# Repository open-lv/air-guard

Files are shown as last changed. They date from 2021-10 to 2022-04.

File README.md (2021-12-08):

# Air Guard 💨



Air Guard is a do-it-yourself electronics kit for building an **air quality monitor** for your school, home or office.

## Project Goals

Create a kit of electronics components, software tools and instructions for kids (and anyone) to create air quality monitors for their living spaces using affordable and readily available components and friendly programming tools.

## Design Goals

- Use existing electronics modules for all components to ensure the parts are available and affordable.

- Build on the experience of other electronics platforms such as [micro:bit](https://microbit.org), [M5Stack](https://m5stack.com), [MicroPython](https://micropython.org), [ESPHome](https://esphome.io) which provide user-friendly tools and concepts for exploring the hardware and software features.

- Allow space for customization and creative expression to encourage use and ownership of the devices.

- Let users experience quick wins early to encourage continued exploration.

- Design for groups of people building the kit and splitting responsibilities.

## Technical Design

- Rely on permanent power supply over USB to avoid limiting the available sensor components (due to their power consumption) and to encourage creative expression in software through the use of LEDs, buzzers and displays. See [issue #4](https://github.com/open-lv/air-guard/issues/4) for the discussion around energy usage.

- Use [MicroPython](https://micropython.org) as the software platform due to the available tooling and accessible programming environments. See [issue #6](https://github.com/open-lv/air-guard/issues/6) for discussion.

- Use ESP32 based microcontrollers due to extensive support for MicroPython and the selected sensor components, and affordable development kits. See [issue #7](https://github.com/open-lv/air-guard/issues/7) for the suggested bill of materials.

## Contribute

Join our [chat on Gitter](https://gitter.im/open-lv/air-guard) to discuss ways to contribute. Issues and pull requests are always welcome!

## Credits

Created [by contributors](https://github.com/open-lv/air-pilot/graphs/contributors).

## License

This is an open source project where the [software](software) and [documentation](docs) are licensed under [MIT](LICENSE) while [the hardware](hardware) is licensed under [CC BY-NC-SA 4.0](hardware/LICENSE).

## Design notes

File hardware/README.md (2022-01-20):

# GAISA SARGS Hardware

GAISA SARGS proto image

GAISA SARGS is an open source air quality monitor DIY kit for kids & teenagers.

Current revision: **03**

Known bugs: **none yet**

Authors: **Skrubis & Zahars Ze**

The project consists of 3 PCBs you need to order:
1) [The main PCB x1 ](https://github.com/open-lv/air-guard/tree/main/hardware/main-pcb) 
2) [The side PCB x2 ](https://github.com/open-lv/air-guard/tree/main/hardware/side-pcb)
3) [The rear PCB x1 ](https://github.com/open-lv/air-guard/tree/main/hardware/rear-pcb)

If you want to practice soldering, feel free to order some "friend" PCBs:
[DRAUGS PCB ](https://github.com/open-lv/air-guard/tree/main/hardware/draugs-pcb)

The PCBs are drawn in Kicad 5.1.x
The schematic of the main board: [airguard_v1.pdf](https://github.com/open-lv/air-guard/blob/main/hardware/main-pcb/airguard_v1.pdf)

All boards are your run of the mill pcbhouse 
(OSH, pcbway, jlcpcb, etc.) standard process compatible. 

Just upload the Gerber ZIP file and choose the options specified below:

Layers: 2

Thicness: 1.6mm

Soldermask color: Blue 
(as intended by the artist Zahars Ze, however we invite you to experiment and show us the results)

Surface finish: RoHS HASL
if used by kids; show us how it looks in ENIG, if you ever make one

The DIY kit BOM can be viewed in the BOM folder, however at this time it is very preliminary in nature. 
Most likely not much will change, but please keep it in mind while viewing it.

**The simple BOM is as follows**:
1) Main PCB - x1
2) Side PCB - x2
3) Rear PCB - x1
4) 19pin 2.54mm female header - x2
5) ESP-32 DevkitC V4 or older version (check pinouts in the main pcb schematic) - x1
6) 4pin 2.54mm female header - x1
7) 5pin 2.54mm female header - x1
8) Winsen MHZ19-C (or -B) - x1
9) 4.7k TH Resistor - x9
10) 2N2222 NPN transistor TO-92 or similar - x4
11) 10mm TH LED Green - 1x
12) 10mm TH LED Red - 1x
13) 10mm TH LED Orange(Yellow) - 1x
14) 3mm TH LED White - 2x
15) 68R TH Resistor - 3x
16) 33R TH Resistor - 2x
17) Buzzer 10mm pin to pin - 1x
18) Standard TH push button 6mm - 1x
19) SSD1306 based I2C OLED 0.96" 128x64px - 1x - check voltage and pinout on the pcb!!
20) 220uF electrolytic capacitor(6.3x11, 25+V)

That's it! It's a very simple project electroncis wise, so feel free to experiment, customize or improve it!

This portion of the project is licensed under [CC BY-NC-SA 4.0](hardware/LICENSE).

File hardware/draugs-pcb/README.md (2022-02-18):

# GAISA SARGS DRAUGS

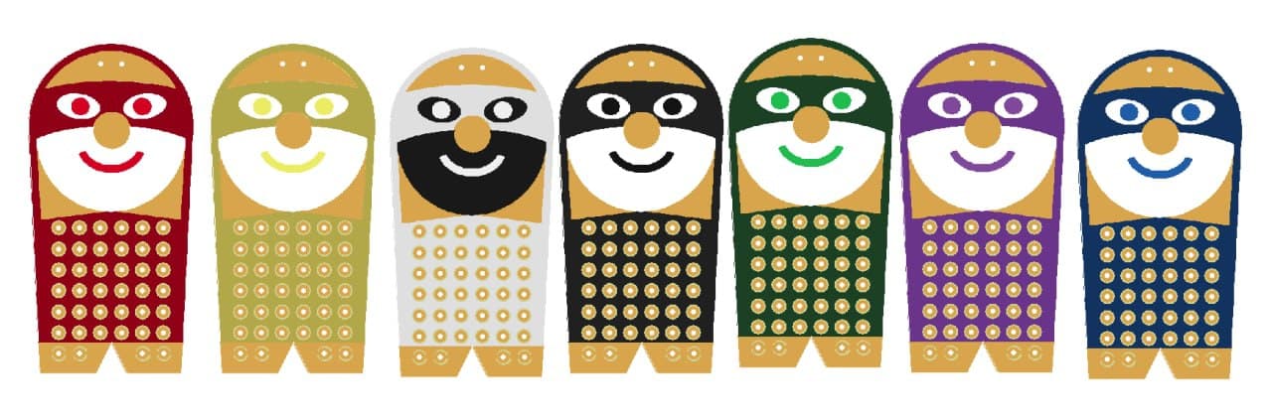
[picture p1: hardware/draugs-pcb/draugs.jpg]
GAISA SARGS draugs


GAISA SARGS DRAUGS is a "learn to solder" PCB

Current revision: **0**

Known bugs: **none yet**

Authors: **Skrubis & Zahars Ze**

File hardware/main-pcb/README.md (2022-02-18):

# GAISA SARGS R03

Version 3 hardware, designed in Kicad 5
by 
SKRUBIS & ZAHARS ZE

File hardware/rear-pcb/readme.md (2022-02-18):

# GAISA SARGS R03 REAR PCB

This pcb acts as a cover for the NDIR CO2 sensor, which may be sensitive to direct sunlight

Version 3 hardware, designed in Kicad 5
by 
SKRUBIS & ZAHARS ZE

KNOWN BUGS: JLCPCB gerber viewer doesn't show or detect the outline, use stackup.txt (found in gerber archive) to specify those

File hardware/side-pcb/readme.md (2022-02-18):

# GAISA SARGS R03 SIDE PCB

This pcb acts as a cover for the NDIR CO2 sensor, which may be sensitive to direct sunlight

You need two of these for one airguard
The slot shape on the side accounts for loose interpretations of Espressifs ESP32 DEVKIT C (may be a bit longer than that of the original design)

Version 3 hardware, designed in Kicad 5
by 
SKRUBIS & ZAHARS ZE

KNOWN BUGS: JLCPCB gerber viewer doesn't show or detect the outline, use stackup.txt (found in gerber archive) to specify those

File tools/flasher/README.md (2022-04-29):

# Air Guard ESP32 Flasher

See [`flash.sh`](./flash.sh) which flashes the core MicroPython firmware and the Air Guard script files. Run it on your local machine if you have `esptool.py`, `ampy` and 'jq' installed or use the included Docker environment. If needed, use brew to add what's missing to your local environment (e.g. 'brew install jq'). 

## Flashing Locally

Install the required Python packages defined in [requirements.txt](./requirements.txt):

    pip install -r requirements.txt

Note that you might need to replace `pip` with `pip3` in the command above depending on your operating system.

Now run the flashing tool which will automatically download the required version of MicroPython firmware, flash it to the device and upload all `*.py` files from the `firmware/micropyhton` directory to the device:

    ESPTOOL_PORT=/dev/tty.usbserial ./flash.sh

where `ESPTOOL_PORT` is the environment variable pointing to the UART port path `/dev/tty.usbserial` with the ESP32 device attached.

## Flashing Using Docker

Note that mounting USB ports inside Docker containers is only supported on Linux host computers. Docker on MacOS and Windows doesn't support this.

Run `docker-compose build` to build the Docker container with the appropriate version of `esptool.py` and `ampy`.

Run `ESPTOOL_PORT=/dev/tty.usbserial docker-compose run --rm flash` to flash the firmware where `/dev/tty.usbserial` is the UART device port path. Alternatively, use the `.env` file to set the `ESPTOOL_PORT` environment variable which will be picked up by `docker-compose` automatically.

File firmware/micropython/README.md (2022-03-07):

MicroPython version of air-guard firmware
--------------------------------------------

The firmware is quite basic at the moment:

  * MHZ19C readings are performed as per datasheet. It appears that during heating phase, it returns a value of 500 (which is misleading and should not be presented to user)
  * main.py intentionally contains the "main" logic, while everything else is hidden under sargs.py. A separate thread is started when importing sargs.py which will handle all the 
  background functionality (re-drawing the screen, connecting to WiFi, publishing readings over MQTT etc)
  * There is comprehensive logging to serial console- do check the console output if something is not working as expected

Startup error conditions
-------------------

  * Blinking red LED: I2C OLED not responding
  * Blinking yellow LED: CO2 sensor not responding

Configuration
----------------------

To enable WiFi functionality, copy the config.json.example file to config.json and enter the configuration details in the file.

To enable publishing to ThingSpeak channel, fill in the following configuration in config.json:
    
  * mqttClientId = "ThingSpeak client ID"
  * mqttPassword = "ThingSpeak MQTT device password"
  * mqttTsId = "ThingSpeak channel ID"
  * mqttClass = "ThingspeakMQTTClient"

CO2 sensor calibration
--------------------------

Manually triggered 400ppm point calibration is implemented. To use it, make sure the sensor is exposed
to ~400ppm (fresh air, outside) for at least 20 minutes before and after starting the calibration.

To start calibration, press the button for at least 5 seconds, then select "Yes" button on confirmation dialog with a short press,
then confirm the start of calibration by long press when "Yes" button is selected.

MicroPython version
-------------------------

This firmware is developed against MicroPython for ESP32 v1.17.

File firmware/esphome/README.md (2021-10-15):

# ESPHome Firmware for Air Guard

See [`air-guard.yaml`](air-guard.yaml) for the firmware configuration.

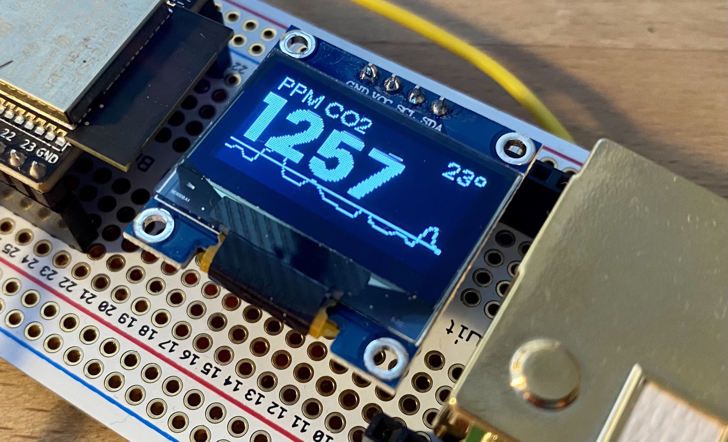
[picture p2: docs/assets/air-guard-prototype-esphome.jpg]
ESPHome showing CO2 sensor values on a display


## Requirements

See the [ESPHome setup instructions](https://esphome.io/guides/getting_started_command_line.html) for how to install the required tooling to compile and upload the firmware. Alternatively, see the "Build and Upload" section below for how to use the ESPHome Docker container to build and upload the firmware.

## Setup

The following pins are used to attach sensors and devices to ESP32:

- MH-Z19B CO2 sensor is connected to UART pins 16 for RX and 17 for TX.
- SSD1306 OLED display is connected to the I2C pins 21 for SDA and 22 for SCL.

## Build and Upload

Copy `secrets.yaml.example` to `secrets.yaml` and configure your WiFi name and password.

Run the following command to build and upload the firmware using the [`esphome` command-line utility](https://esphome.io/guides/cli.html):

    esphome run air-guard.yaml

Alternatively, use the ESPHome Docker container to do the same:

    docker run --rm --volume "${PWD}":/config --device=/dev/ttyUSB0 --privileged --interactive --tty esphome/esphome run air-guard.yaml

where `/dev/ttyUSB0` is the absolute path to the serial interface on the host computer to be shared with the Docker container for uploading the firmware. The `--privileged` flag might not be necessary depending on your operating system and Docker configuration.

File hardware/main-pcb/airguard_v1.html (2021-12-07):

# C:\Users\Work\Desktop\air-guard-non-square\hardware\airguard_v1.sch

11/09/21 10:31:13 PM

Eeschema (5.1.10)-1

Component Count:39

Ref | Qnty | Value | Part | Datasheet | Description | Vendor
BZ1 | 1 | Buzzer | Device:Buzzer | ~ | Buzzer, polarized
DZELTENS1 | 1 | LED_YELLOW | Device:LED | ~ | Light emitting diode
J1, J3 | 2 | Conn_01x04_Female | Connector:Conn_01x04_Female | ~ | Generic connector, single row, 01x04, script generated (kicad-library-utils/schlib/autogen/connector/)
J2 | 1 | Conn_01x05_Female | Connector:Conn_01x05_Female | ~ | Generic connector, single row, 01x05, script generated (kicad-library-utils/schlib/autogen/connector/)
J4, J5 | 2 | Conn_01x19_Female | Connector:Conn_01x19_Female | ~ | Generic connector, single row, 01x19, script generated (kicad-library-utils/schlib/autogen/connector/)
Q1, Q2, Q3, Q4 | 4 | PN2222A | Transistor_BJT:PN2222A | https://www.onsemi.com/pub/Collateral/PN2222-D.PDF | 1A Ic, 40V Vce, NPN Transistor, General Purpose Transistor, TO-92
R1, R2, R3, R4, R6, R7, R8, R9, R10 | 9 | R 4.7K | Device:R | ~ | Resistor
R5 | 1 | R_PHOTO 8-20kR | Device:R_PHOTO | ~ | Photoresistor
R11, R12, R13 | 3 | 68R | Device:R | ~ | Resistor
SARKANS1 | 1 | LED_RED | Device:LED | ~ | Light emitting diode
SW1 | 1 | SW_Push | Switch:SW_Push | ~ | Push button switch, generic, two pins
U1 | 1 | MH-Z19B | mh_z19b:MH-Z19B
U2 | 1 | ESP32_DEVKIT_C | esp32_devkitc:ESP32_DEVKIT_C
U3 | 1 | SSD1306 | SSD1306-128x64_OLED:SSD1306
U4, U5, U6, U7, U8, U9 | 6 | Solder-rib-main | gaisa-sargs-0:Solder-rib-main
U10 | 1 | ART-FCOPPER | gaisa-sargs-0:ART
U11 | 1 | ART-FSILK | gaisa-sargs-0:ART
U12 | 1 | ART-FMASK | gaisa-sargs-0:ART
ZAĻŠ1 | 1 | LED_GREEN | Device:LED | ~ | Light emitting diode

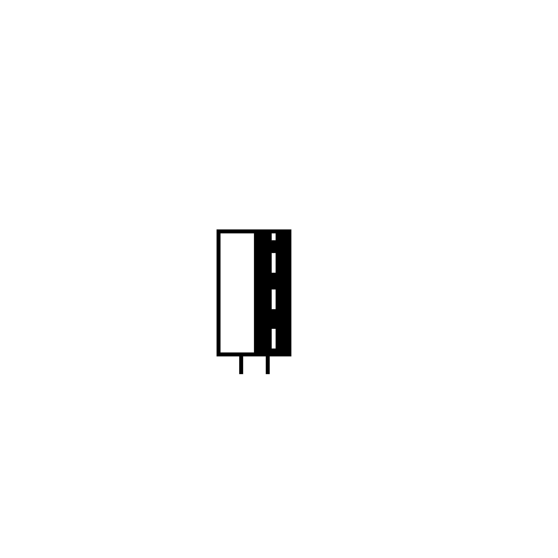
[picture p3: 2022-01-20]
hardware/main-pcb/pcbart/cancap/.svg2shenzhen-cache/images/F.SilkS_g8889.png

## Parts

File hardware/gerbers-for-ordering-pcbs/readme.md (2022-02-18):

Use these archives to order copies.
Inspect the archives for stackup.txt to find out what options you should choose for the PCB house.

Known bugs: JLCPCB viewer doesn't find the outline for side and rear PCBs, refer to the stackup.txt file

Possible PCB fab houses: OSHPARK, JLCPCB, PCBWAY, ALLPCB, DIRTYPCBS, EUROCIRCUITS, AISLER, ETC

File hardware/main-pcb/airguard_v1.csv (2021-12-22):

Reference | Value | Footprint | Datasheet | LCSC | LCSC URL | MPN | SOURCE
U2 | ESP32_DEVKIT_C | footprints:ESP32_DEVKIT_C
U1 | MH-Z19B | footprints:Winsen_MH-Z19B
U3 | SSD1306 | footprints:SSD1306
Q2 | PN2222A | TO_SOT_Packages_THT:TO-92_Molded_Wide | https://www.onsemi.com/pub/Collateral/PN2222-D.PDF | C118536 | https://lcsc.com/product-detail/Bipolar-Transistors-BJT_ST-Semtech-2N2222A_C118536.html
SARKANS1 | LED_RED | LEDs:LED_D10.0mm | ~ |  |  | szczine | szczine@163.com
R11 | 68R | Resistors_ThroughHole:R_Axial_DIN0207_L6.3mm_D2.5mm_P10.16mm_Horizontal | ~ | C385542 | https://lcsc.com/product-detail/Through-Hole-Resistors_TyoHM-RN1-2WS68-FT-BA1_C385542.html
Q3 | PN2222A | TO_SOT_Packages_THT:TO-92_Molded_Wide | https://www.onsemi.com/pub/Collateral/PN2222-D.PDF | C118536 | https://lcsc.com/product-detail/Bipolar-Transistors-BJT_ST-Semtech-2N2222A_C118536.html
DZELTENS1 | LED_YELLOW | LEDs:LED_D10.0mm | ~ |  |  | szczine | szczine@163.com
Q4 | PN2222A | TO_SOT_Packages_THT:TO-92_Molded_Wide | https://www.onsemi.com/pub/Collateral/PN2222-D.PDF | C118536 | https://lcsc.com/product-detail/Bipolar-Transistors-BJT_ST-Semtech-2N2222A_C118536.html
ZALS1 | LED_GREEN | LEDs:LED_D10.0mm | ~ |  |  | szczine | szczine@163.com
SW1 | SW_Push | Buttons_Switches_ThroughHole:SW_PUSH_6mm_h5mm | ~ | C393938 | https://lcsc.com/product-detail/Tactile-Switches_SHOU-HAN-TS665CJ_C393938.html
J4 | Conn_01x19_Female | Oddities:Dummy_Empty | ~ | C319202 | https://lcsc.com/product-detail/Female-Headers_BOOMELE-Boom-Precision-Elec-C319202_C319202.html
J5 | Conn_01x19_Female | Oddities:Dummy_Empty | ~ | C319202 | https://lcsc.com/product-detail/Female-Headers_BOOMELE-Boom-Precision-Elec-C319202_C319202.html
J3 | Conn_01x04_Female | Oddities:Dummy_Empty | ~ | C2718488 | https://lcsc.com/product-detail/Female-Headers_BOOMELE-Boom-Precision-Elec-C2718488_C2718488.html
J1 | Conn_01x04_Female | Oddities:Dummy_Empty | ~ | C2718488 | https://lcsc.com/product-detail/Female-Headers_BOOMELE-Boom-Precision-Elec-C2718488_C2718488.html
J2 | Conn_01x05_Female |  | ~
R5 | R_PHOTO 8-20kR | Opto-Devices:Resistor_LDR_5.1x4.3_RM3.4 | ~ | C125627 | https://lcsc.com/product-detail/Photoresistors_Senba-Sensing-Tech-GL5528_C125627.html
R4 | R 4.7K | Resistors_ThroughHole:R_Axial_DIN0207_L6.3mm_D2.5mm_P10.16mm_Horizontal | ~ | C120071 | https://lcsc.com/product-detail/Through-Hole-Resistors_CCO-Chian-Chia-Elec-CF1-4W-4-7K-5-T52_C120071.html
BZ1 | BALSS | footprints:buzzer-C360606 | ~ | C360606 | https://lcsc.com/product-detail/Buzzers_S-S-SFN-1207PA5-0_C360606.html
Q1 | PN2222A | TO_SOT_Packages_THT:TO-92_Molded_Wide | https://www.onsemi.com/pub/Collateral/PN2222-D.PDF | C118536 | https://lcsc.com/product-detail/Bipolar-Transistors-BJT_ST-Semtech-2N2222A_C118536.html
R7 | R 4.7K | Resistors_ThroughHole:R_Axial_DIN0207_L6.3mm_D2.5mm_P10.16mm_Horizontal | ~ | C120071 | https://lcsc.com/product-detail/Through-Hole-Resistors_CCO-Chian-Chia-Elec-CF1-4W-4-7K-5-T52_C120071.html
R8 | R 4.7K | Resistors_ThroughHole:R_Axial_DIN0207_L6.3mm_D2.5mm_P10.16mm_Horizontal | ~ | C120071 | https://lcsc.com/product-detail/Through-Hole-Resistors_CCO-Chian-Chia-Elec-CF1-4W-4-7K-5-T52_C120071.html
R9 | R 4.7K | Resistors_ThroughHole:R_Axial_DIN0207_L6.3mm_D2.5mm_P10.16mm_Horizontal | ~ | C120071 | https://lcsc.com/product-detail/Through-Hole-Resistors_CCO-Chian-Chia-Elec-CF1-4W-4-7K-5-T52_C120071.html
R6 | R 4.7K | Resistors_ThroughHole:R_Axial_DIN0207_L6.3mm_D2.5mm_P10.16mm_Horizontal | ~ | C120071 | https://lcsc.com/product-detail/Through-Hole-Resistors_CCO-Chian-Chia-Elec-CF1-4W-4-7K-5-T52_C120071.html
R3 | R 4.7K | Resistors_ThroughHole:R_Axial_DIN0207_L6.3mm_D2.5mm_P10.16mm_Horizontal | ~ | C120071 | https://lcsc.com/product-detail/Through-Hole-Resistors_CCO-Chian-Chia-Elec-CF1-4W-4-7K-5-T52_C120071.html
R12 | 68R | Resistors_ThroughHole:R_Axial_DIN0207_L6.3mm_D2.5mm_P10.16mm_Horizontal | ~ | C385542 | https://lcsc.com/product-detail/Through-Hole-Resistors_TyoHM-RN1-2WS68-FT-BA1_C385542.html
R13 | 68R | Resistors_ThroughHole:R_Axial_DIN0207_L6.3mm_D2.5mm_P10.16mm_Horizontal | ~ | C385542 | https://lcsc.com/product-detail/Through-Hole-Resistors_TyoHM-RN1-2WS68-FT-BA1_C385542.html
R10 | R 4.7K | Resistors_ThroughHole:R_Axial_DIN0207_L6.3mm_D2.5mm_P10.16mm_Horizontal | ~ | C120071 | https://lcsc.com/product-detail/Through-Hole-Resistors_CCO-Chian-Chia-Elec-CF1-4W-4-7K-5-T52_C120071.html
R1 | R 4.7K | Resistors_ThroughHole:R_Axial_DIN0207_L6.3mm_D2.5mm_P10.16mm_Horizontal | ~ | C120071 | https://lcsc.com/product-detail/Through-Hole-Resistors_CCO-Chian-Chia-Elec-CF1-4W-4-7K-5-T52_C120071.html
R2 | R 4.7K | Resistors_ThroughHole:R_Axial_DIN0207_L6.3mm_D2.5mm_P10.16mm_Horizontal | ~ | C120071 | https://lcsc.com/product-detail/Through-Hole-Resistors_CCO-Chian-Chia-Elec-CF1-4W-4-7K-5-T52_C120071.html
J6 | Conn_01x04_Female | Oddities:Dummy_Empty | ~ | C2718488 | https://lcsc.com/product-detail/Female-Headers_BOOMELE-Boom-Precision-Elec-C2718488_C2718488.html
R15 | 33R | Resistors_ThroughHole:R_Axial_DIN0207_L6.3mm_D2.5mm_P10.16mm_Horizontal | ~ | C120071 | https://lcsc.com/product-detail/Through-Hole-Resistors_CCO-Chian-Chia-Elec-CF1-4W-4-7K-5-T52_C120071.html
D2 | LED | footprints:LED_D3.0mm | ~
R14 | 33R | Resistors_ThroughHole:R_Axial_DIN0207_L6.3mm_D2.5mm_P10.16mm_Horizontal | ~ | C120071 | https://lcsc.com/product-detail/Through-Hole-Resistors_CCO-Chian-Chia-Elec-CF1-4W-4-7K-5-T52_C120071.html
D1 | LED | footprints:LED_D3.0mm | ~

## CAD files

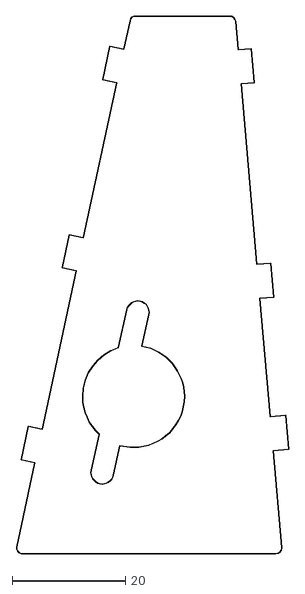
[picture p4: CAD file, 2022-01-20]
hardware/side-pcb/side-rib-3.dxf
48.1 x 94.9

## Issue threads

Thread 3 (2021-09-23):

Plates (PCB) forma un noformējums

kasparsd, 2021-09-23:
Kāda varētu būt PCB kontūra un noformējums, lai tas liktos interesants un iederētos klasēs un birojos?

Svarīgi ņemt vērā ārējo izmēru (cena) un praktiskās iespējas tādu formu saražot pietiekami mazos kvantumos, lai pieļautu izmaiņas. Pirmajām partijām varētu izmantot https://jlcpcb.com vai https://www.pcbway.com

kasparsd, 2021-09-23:
Te ir jaunākais variants, kas ir mazliet draudzīgāks par vienkārši zaļu plati:

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

martinsp, 2021-09-25:
Vai nevajadzētu samainīt vietām bateriju turētāju un radošo laukumu? Domāju, vai komponentes uz plates netraucēs rokai, lai varētu uzzīmēt/uzrakstīt kaut ko radošajā laukumā.

kasparsd, 2022-01-04:
Taisām ciet, jo šis jau ir izdarīts!

Closed 2022-01-04.

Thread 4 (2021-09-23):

CO2 sensora enerģijas patēriņš un deep-sleep atbalsts

kasparsd, 2021-09-23:
Vai kādi no pieejamajiem sensoriem piedāvā zemu enerģijas patēriņu vai deep-sleep atbalstu, lai būtu iespējams visu iekārtu darbināt tikai no 2 gab AA baterijām vismaz vienu gadu?

festlv, 2021-09-23:
1 gada darbības laiks no 2xAA baterijām ir netriviāls uzdevums, kura risināšanai var nākties pabīdīt citus constraintus (gatavu ESP32 moduļu izmantošana, viegla montāža).

Kvalitatīvās 2xAA baterijās ir ap 6Wh enerģijas. Lai gadu darbinātu no šādām baterijām, vidējam patēriņam no baterijām jābūt ~210uA@3.3V.

Sensirion SCD41 pietuvojas šim (datasheet sola 400uA vidējo patēriņu mērot reizi 5 minūtēs), bet stockā pašlaik redzu 5 gab. ar nākamajām piegādēm decembrī.

kasparsd, 2021-09-24:
Paldies par izpēti @festlv!

Izskatās, ka konkrētajam TTGO T5 modelim ir vairākas lietas, kam jāpievērš uzmanību, lai dabūtu zemu enerģijas patēriņu pat pie ESP32 deep-sleep. Te ir labs pavediens https://github.com/esphome/issues/issues/1458

1. CP2104 UART uz USB čips, kam "enable" kāja ir pie USB 5V, tāpēc cerams, ka tas vispār netiek darbināts, kad darbojas no baterijas.

2. W25Q32FW flash čipam CS kāja esot atstāta gaisā, kas nozīmē, ka pie ESP32 deep sleep tas joprojām darbojas https://github.com/esphome/issues/issues/1458#issuecomment-813915856

   > TTgo has bad energy efficiency design, biggest easy fix is a pullup on w25q32 spiflash CS pin, without it spiflash does not go to sleep even when MCU is sleeping, this has a significant impact on sleep consumption. Removing all LEDs helps also.

3. E-paper draiverim ir jāpadod speciāla komanda gulēšanai, jo citādi tas arī paliek nomodā.

Šodien mēģināju to TTGO T5 ar esphome deep-sleep, bet pieslēgtu pie USB un dabūju 9mA@5V ar ieslēgtiem LEDiem. Ar wifi un ekrāna zīmēšanu patēriņš ir pie 50-70mA @ 5V.

Domāju, ka jāsāk apsvērt micropython, jo tad varam vairāk kontrolēt izmantotās bibliotēkas, driverus un arī pašu izejas kodu. Vienīgi tad mums vajag Micropython draiverus gan ekrānam (HINK E0213A22), gan sensoriem. Nezinu, vai ir kaut kas gatavs.

kasparsd, 2021-09-24:
Un vēl viena potenciālā problēma ar TTGO T5 ir iebūvētais TP4054 lādēšanas kontrolieris, kas atbalsta tikai litija jonu akumulatorus. Tas nozīmē, ka AA baterijas nevarēs slēgt pa taisno pie esošā BAT pieslēgvietas, jo tad, pieslēdzot USB 5V, tas gribēs lādēt AA vai AAA, kā li-ion.

Anrijs, 2021-09-25:
Notestēju TTGO T5 V2.3 pie precīzāka mēraparāta. Deep-sleep rādīja 1.0-1.5mA patēriņu. Visi LED izslēgti, tukšs kods. Tajā pašā laikā, mana custom plate tērē zem 100uA.

kasparsd, 2021-09-25:
Liels paldies @Anrijs! Vai būtu iespējams pārbaudīt vai pull-ups pie W25Q32FW CS kājas tiešām samazina šo vēl 10x kā daži raksta?

Interesanti, ka [jaunākajam TTGO T5 V2.3.1](http://www.lilygo.cn/prod_view.aspx?TypeId=50031&Id=1393&FId=t3:50031:3) viņi sola 300uA:

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

Ja 90% laika tiešām ir tie 300uA un pie e-paper zīmēšanas uzlec 50mA, tad vajadzētu būt OK, ne? Vienīgi jāmāk pamodināt iekārtu no deep-sleep, kad piesprauž USB kabeli programēšanai.

> Tajā pašā laikā, mana custom plate tērē zem 100uA.

Vai tas ir ar ESP32?

Kāds ir tavas domas, ko šajā gadījumā labāk darīt, ja uzdevums prasa pēc ekrāna un plaši pieejamiem moduļiem?

Anrijs, 2021-09-25:
Pieleiku 10k pullup (lielāku uz ātro neatradu). Tagad rāda 400-500uA. Mana plate ir ar ESP32 WROOM-32D moduli.
Ja neizmanto šo TTGO gatavo risinājumu, tad jāskatās kas vispār no e-ink ir pieejams saprātīgās cenās. Ir variants zīmēt plati uz kuras to ESP32 moduli un citas komponentes salodē pa tiešo.

kasparsd, 2021-09-25:
> Tagad rāda 400-500uA.

Šis jau ir diezgan labi, ne! Vismaz tagad izklausās ticami, ka tas jaunais variants V2.3.1 sola 300uA.

Ja liek klāt SCD41 sensoru (450uA), tad sanāk ap 1mA. Ja pieliek vēl e-paper refresh reizi 5 minūtēs (pie SDC41 lasījuma), tad gan jau salasīsies visi 2mA. Ar 2000mA bačām sanāk 1000h jeb mazliet pāri mēnesim. Man šķiet pieņemami, ka reizi mēnesī kāds piespraustu sensoru pie USB aku-bankas uzlādēties.

Ar MH-Z19b gan ir trakāk, jo tam vidējais patēriņš pie ieslēgta ir ap 17mA un iesilšanas ilgums 3min. Nezinu, cik daudz viņš spētu atdzist pa piecām minūtēm, bet kopumā pat ar 50% izslēgtu barošanu sanāk lielas problēmas. Un šī ir ilustratīva problēma visiem NDIR sensoriem. Bet toties tie ir pieejami.

Ja SAFs tiešām var nodrošināt 100 gab ar SCD41, tad varētu uztaisīt savu moduli ar through-hole kājām, jo pliks virsmas montāžas sensors maksā ap EUR 30 un spriežot pēc [Seeed moduļa](https://wiki.seeedstudio.com/Grove-CO2_%26_Temperature_%26_Humidity_Sensor-SCD41/), nekādi pasīvie elementi nav vajadzīgi.

Lai nepārvērstu šo par enerģijas patēriņa optimizācijas uzdevumu, varbūt jāsāk pieņemt, ka šāds moduļveidīgs dizains pieļauj tikai pāris dienas/nedēļas/mēnešus ar baterijām un primāro lietojumu jāplāno kā iekārtu, kas pieslēgta pie patstāvīgas barošanas.

ArtursGailis1995, 2021-09-25:
Pašam ir sataisīts energo-nedraudzīgs risinājums uz ESP32, LCD, BME280, DHT22, un priekš CO2 ir MHZ-19B sensors. Diez vai šim projektam der NDIR sensori. Dati pa WiFi sūtas uz InfluxDB serveri un attēlojas ar Grafana, lai varu redzēt arī tendences, ne tikai esošos mērījumus. Viss jau pāris gadus barojas no veca iPhone lādētāja, bet varbūt šis projekts pamudinās kaut ko optimizēt vai vismaz pamērīt patēriņu.

Šāds tāds kods man ir arī Githubā, bet tur galīgi viss pa mežam, sen nav atjaunots.

kasparsd, 2021-09-25:
@ArtursGailis1995 Izskatās, ka Tev jau ir praktiski gatavs tas, ko mēģinām uzbūvēt :) Vai būtu iespējams padalīties ar bildi, kur Tev šī iekārta stāv telpā un kā izskatās?

Un smieklīgi, ka šodien tieši nolēmām atteikties no energo-efektīvā risinājuma, lai nebūtu jāoptimizē lietas, kas nav svarīgas tieši izglītības aspektam. Taisīsim slēdzamu pie patstāvīgas barošanas un tad ar visiem LEDiem un pīkstuļiem, lai jautrāk. Te ir sarakstes sākums https://gitter.im/open-lv/air-guard?at=614f51158065e87a8e027450

kasparsd, 2021-09-25:
Tā kā šodien izlēmām atteikties no bateriju barošanas, tad šo jautājumu pagaidām uzskatām par slēgtu. Ja būs vajadzība pēc bateriju darbināmas ierīces, tad arī meklēsim sensorus un komponentes, kas to atbalsta. Projekta MVP fāzē nebūtu prātīgi koncentrēties uz tehnisku optimizācijas uzdevumu, kad vēl nav saprastas kopējās prioritātes un vajadzības.

Closed 2021-09-25.

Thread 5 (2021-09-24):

Lietošanas instrukcijas un metodiskais materiāls visvienkāršākajam pielietojumam

kasparsd, 2021-09-24:
Lai samazinātu risinājuma atkarību no specializētiem rīkiem (lodāmurs) vai programnodrošinājuma (konfigurēts tool-chain), iesaku koncentrēties uz visvienkāršāko projekta pielietojumu:

1. Klase saņem un izpako komplektu, kurā ir PCB ar spraužamām ligzdām un visas komponentes -- kontrolieris, sensors, baterijas.

2. Skolēni iepazīstas ar lietošanas instrukciju un saprot, kurš modulis jāsprauž kurā vietā.

3. Tiek sasprausti moduļi un ieliktas baterijas, un ieslēgta iekārta.

4. Skolēni izdomā un uzraksta savas iekārtas nosaukumu vai logo uz atvēlētā laukuma. Novietu iekārtu tai atvēlētā vietā.

Bonus lietas:

- Grupa izrunā un izpēta, ko nozīmē "labs" gaiss, un cik daudz svaiga gaisa cilvēkam nepieciešams. Var atsaukties uz 20-30m3/h, kā to iesaka Passive House standarts.

- Grupas izpēta katru sastāvdaļu un sagatavo prezentāciju par to, kā tās strādā.

- Grupa izpēta un saprot, kādas ir atbilstošas vietas sensora novietošanai.

- Grupa izdomā stratēģiju, kā izmantot sensora datus -- ko darīt, kad sasniegtas konkrētas vērtības. Varbūt dežuranti, kas atbildīgi par datu uzraudzību un klases ventilēšanu atbilstoši izdomātajai stratēģijai?

Closed 2022-01-20.

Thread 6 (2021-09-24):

Programēšanas platforma projektam

kasparsd, 2021-09-24:
Tā kā šis ir izglītojošs projekts, tad vajadzīga tāda platforma, kuru ir viegli darbināt bez specializēta programnodrošinājuma.

Gan BBC Micro:bit, gan M5 Stack izmanto Micropython, jo tam ir sekojoši labumi:

- Ierīces atmiņā atrodas konstants firmware un lietotāja programnodrošinājums tiek definēts Python skriptos, kas glabājas kā "faili" flash atmiņā.
- Visas lietotāja programmas iespējams ielasīt, pieslēdzoties ar UART. Jebkuru programmu var rediģēt, kā arī pievienot jaunu.
- Pieejama REPL saskarsne, kas ļauj lietotājiem darbināt kontroliera funkcijas bez jauna programnodrošinājuma ielādes.
- REPL saskarsni var darbināt arī caur Web USB, izmantojot jebkuru tīmekļa pārlūku, kas to atbalsta.
- Pieejams programnodrošinājums visām operētājsistēmām, lai rediģētu un pievienotu jaunas programmas -- https://codewith.mu un https://thonny.org
- MicroPython ir Python, kas ir ļoti populāra un noderīga programēšanas valoda.

Izvēloties MicroPython, ir jāatrod vai jāuzraksta draiveri izvēlētajiem sensoriem vai arī jāizvēlas tādas komponentes, kam jau ir MicroPython atbalsts.

- ✅  Waveshare e-paper https://github.com/mcauser/micropython-waveshare-epaper
- ✅   MHZ19 ir vienkāršs PWM protokols https://github.com/antrew/mh-z19/blob/315af72d848e05c32c74d3ea930d94d15c80e227/MHZ19.cpp
- SCD41 ir labi dokumentēts i2c protokols https://github.com/Sensirion/embedded-i2c-scd4x

festlv, 2021-09-25:
Draiveru esamība/neesamība manuprāt nav iemesls, lai neizmantotu MicroPython: nepieciešamības gadījumā trūkstošais būs jāuzraksta, bet tas attiecas uz jebkuru platformu: ja projekts nebalstās uz izstrādes komandas iepriekš validētu hw/sw kombināciju, pastāv zināms risks, ka kaut kam nebūs draiveru, vai tajos nebūs realizēta vajadzīga fīča, vai būs kritiskas problēmas.

MicroPython izmantošanai profesionālā vidē es tik viegli nepiekristu, bet šāda projekta kontekstā nevaru iedomāties nevienu vērā ņemamu risku, kas izrietētu no MicroPython izmantošanas.

kasparsd, 2021-09-26:
Pēc diskusijas čatā un šeit ir nolemts izmantot MicroPython. Tas ir aprakstīts arī projekta tehniskajās vadlīnījās https://github.com/open-lv/air-guard/blob/92e274c4fb08f116cc48bd734bb726daccee3572/README.md#technical-design

Closed 2021-09-26.

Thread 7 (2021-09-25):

Materiālu saraksts (bill of materials) -- kontrolieri, sensori un barošana

kasparsd, 2021-09-25:
Provizoriskais materiālu saraksts (atjaunots 26. septembrī):

## Vietas sensoriem

- [MH-Z19b](https://www.winsen-sensor.com/sensors/co2-sensor/mh-z19b.html) CO2 sensors.
- DHT22 temperatūras un mitruma sensors.

Tukša vieta uz PCB vēl šādiem:

- [SenseAir S8](https://senseair.com/products/size-counts/s8-residential/) CO2 sensors.
- [SCD41](https://www.sensirion.com/en/environmental-sensors/carbon-dioxide-sensors/carbon-dioxide-sensor-scd4x/) CO2, temperatūras, mitruma un trokšņa sensors. Šis ir surface-mount, tāpēc vajadzīga pārejas plate vai arī atbalsts esošiem moduļiem.
- [BME280](https://randomnerdtutorials.com/dht11-vs-dht22-vs-lm35-vs-ds18b20-vs-bme280-vs-bmp180/) temperatūras un mitruma sensors.

## Barošana

Tika izlemts lietot patstāvīgu barošanu no USB, lai MVP versijā nebūtu jānodarbojas ar enerģijas patēriņa optimizācijas uzdevumu.

## Kontrolieris un ekrāns

- ESP32-DevKitC
- SSD1306 OLED ekrāns

Anrijs, 2021-09-26:
MH-Z19B/C boost vajadzēs uz 5V

kasparsd, 2021-09-26:
Izskatās, ka ESP32-DevKitC [padod USB 5V uz EXT_5V kāju](https://dl.espressif.com/dl/schematics/esp32_devkitc_v4-sch.pdf), kad pieslēgts USB:

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

Vai pareizi saprotu?

Šis, protams, der tikai tad, ja tiek lietots patstāvīgs USB pieslēgums, par kuru vakar nolēmām čatā.

Anrijs, 2021-09-26:
Ja barošana paliek tikai no USB, tad var no tā EXT 5V pin barot

kasparsd, 2021-09-27:
ESP32 devkitc piegādātāju opcijas:

- https://www.olimex.com/Products/IoT/ESP32/ESP32-DevKit-LiPo/open-source-hardware
- https://www.tme.eu/lv/details/esp32-devkitc-32d/komplekts-datu-transmisijai/espressif/
- https://www.az-delivery.de/en/products/esp-32-dev-kit-c-v4?variant=30871551901792

kasparsd, 2021-09-27:
Esmu pasūtījis kopumā 15 gab. devkitc no diviem piegādātājiem un varēšu pārsūtīt visiem interesentiem.

kasparsd, 2021-10-09:
Iedomājos, ka varētu paredzēt vietu vēl sekojošām komponentēm:

- on/off slēdzis. Var likt pie `EN` kājas, bet tas izslēdz tikai 3.3V barošanu pašam ESP32 un visam, kas barojas no tiem 3.3V. Alternatīva ir paredzēt vietu savam USB virsmaz montāžas štepselim uz plates, kas var pilnībā izslēgt visu iekārtu. Pieslēgvieta uz plates arī atļautu optimizēt tās novietojumu, lai plate negāztos uz galda vai nesvērtos pie sienas.

- Passive buzzeris, kas nodzied bēdīgu meldiņu, kad pārsniedz 1400PPM un priecīgu, kad ir atpakaļ zem 600 vai jebkuras citas iedomātas robežas. Buzzerim vajadzētu savu slēdzi, lai var apklusināt bez pārprogramēšanas. Šiem parasti ir divas kājas, kuras var iespraust ligzdā.

- Kaut kādus ledus? Varbūt zaļu, dzeltenu un sarkanu vai vairākus rindā, lai atvieglotu CO2 nolasīšanu no attāluma, jo dzīvē tas SSD1306 ir tiešām maziņš un blāvs?

Anrijs, 2021-10-11:
`EN` varbūt labāk neaiztikt. Tas tiek izmantots priekš programmēšanas.
Buzeris varētu būt noderīgs, bet tam jātaisa driveris vai jāmeklē gatava plate ar driveri. Slēgt vienu kāju pa tiešo pie ESP32 nebūs labs variants.
LED varētu būt noderīgi, lai var redzēt stāvokli arī no otra telpas stūra.

Closed 2022-01-20.

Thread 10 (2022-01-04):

Basic firmware in MicroPython that supports data display (OLED + 3 LEDs) and sensor calibration.

kasparsd, 2022-01-04:
Šis būtu pats minimums, ko vajadzētu nodrošināt, lai iekārta būtu funkcionāla (bet ne pārāk interesanta):

- Attēlo CO2 PPM uz ekrāna.
- LED uz rokas deg:
   - Zaļš, ja zem 700ppm
   - Dzeltens starp 700-1400ppm
   - Sarkans virs 1400ppm
- Pārsniedzot 1400ppm iepīkstas pīkstulis trīs reizes.
- Nospiežot rokas pogu ilgāk par 5 sekundēm tiek sākta kalibrēšanas procedūra.

Viss augstāk minētais ir diskutējams un maināms.

kasparsd, 2022-01-04:
Bonus punkti par #12, kas piešķir iekārtai mākoņa spējas.

kasparsd, 2022-01-04:
Te ir prototips no @festlv https://wokwi.com/arduino/projects/319303888677110355

festlv, 2022-01-08:
Par CO2 sliekšņiem- varbūt pieturēties pie Aranet sliekšņiem (1000, 1000-1400, 1400+)?

Pašreizējais MicroPython todo:
* Pārliecināties, ka kāds neapstrādāts exception nerezultējas iefrīzojušā sargā,
* MHZ19C kontrolsummas rēķināšana ir kļūdaina, pieliku debug kodu, jāsagaida kad reproducēsies,
* Ieslēgt kalibrāciju (domāju ne tikai 5s nospiestu pogu, bet ar apstiprināšanu uz ekrāna)
* Ieslēdzoties detektēt sensora uzsilšanu (pēc novērojumiem, atgriež vērtību 500 daždesmit sekundes pēc starta, bet droši vien ir kāds statusa bits neoficiāli dokumentētajās komandās)
* Pīkstuļa iepīkstēšanās pārsniedzot 1400 (ar laika/mērījuma histerēzi)

festlv, 2022-01-11:
Vēl no TODO:
* Izslēgt automātisko nulles punkta kalibrāciju (saskaņā ar sensora dokumentāciju tā ir ieslēgta pēc noklusējuma)
* Build process kas ieraksta firmware versiju kādā .py failā
* Pīkstēšana pie kalibrācijas ieslēgšanas

kasparsd, 2022-01-11:
> Build process kas ieraksta firmware versiju kādā .py failā

Tu domā kaut kādu visa .py kopuma versiju? Varbūt iemest to kā pēdējo tajā `config` datnē?

To tad sūtītu ar MQTT ziņām, piemēram? Un rādītu uz ekrāna kaut kur?

festlv, 2022-01-11:
Jā, build procesa rezultāts būtu arhīvs ar py failiem, iespējams flasher skriptiem. Tas būtu piemērots brīdis arī vai nu config.py vai iekš sargs.py iemest __VERSION__ vai kāda nu bija pitona konvencija versijas glabāšanai. Pašu versiju esmu pieradis ņemt no git taga (ja commitam nav atbilstoša taga, tad pēdējais tags + commit hash.

Izmantot: parādīt uz ekrāna pēc ieslēgšanās, mqtt, kā arī ielogot pie startupa seriālajā konsolē.

Closed 2022-02-17.

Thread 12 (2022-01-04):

On-device webpage for configuring wifi credentials and remote data logging opt-in to our MQTT endpoint

kasparsd, 2022-01-04:
Ierīces web serveris ļauj ieslēgt (1) datu sūtīšanu un (2) attēlošanu Gaisa sarga “mākonī”.

Ja datu sūtīšana ieslēgta, tad iekārta reizi minūtē sūta MQTT ziņu uz `mqtt.gaisasargs.lv:1883`, kurā norāda:
MQTT servisa piekļuves dati:

- Lietotājs: iekārtas MACID ([a-z0-9]{12})
- Parole: Pirmie četri baiti no MicroPython `machine.unique_id()` HEX pierakstā ([a-z0-9]{8})

Sūtījuma dati:

- CO2 mērījums (int)
- Temperatūras mērījumu (int, jo sensors to dod neprecīzu)
- Publisko datu attēlošanas atļauja (boolean)

kasparsd, 2022-01-14:
@festlv Cik sarežģīti ir uztaisīt kaut ko no šī? Vai ir jau kādas gatavas bibliotēkas, kas nodrošina web serveri un kaut kādu konfigurācijas parametru kartēšanu uz mainīgo vērtībām?

festlv, 2022-01-14:
Pašlaik vēl neesmu pētījis, @RonnyLV izrādīja interesi palīdzēt ar šo uzdevumu.
Vienīgā piezīme, ka man izskatās, ka MicroPython machine.unique_id() atgriež to pašu MAC adresi.

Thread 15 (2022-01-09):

Hardware change list for rev3

festlv, 2022-01-09:
* 220uF electrolytic capacitor near ESP32/MHZ19
* Fatter 5V/GND traces (at least from ESP32 to MHZ19)

Closed 2022-01-20.

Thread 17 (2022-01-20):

Fix Rear PCB & Side PCB boundaries

skrubis, 2022-01-20:
For some reason JLCPCB can not detect pcb dimensions from the boundaries, thus making the ordering process more painful if not using the stackup file for manual dimension entry

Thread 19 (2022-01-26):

draugs pcb fix design for manufacturability

skrubis, 2022-01-26:
remove track from between legs to not confuse the fab with what to do with the outline

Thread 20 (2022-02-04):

Main screen UI

skrubis, 2022-02-04:
Recreate micropython version of platformio oled UI. nice to have- animated sprite for heart.
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

skrubis, 2022-02-04:
this is somewhat of a pain point as it kinda holds back other processes - namely video assembly manuals, other docs, printed media

Closed 2022-02-14.

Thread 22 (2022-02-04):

Buzzer sounds

skrubis, 2022-02-04:
Create a bunch of sounds for various emotions:
1)soft attention - upon change of environment (lights on)
2)attention - upon need to open a window
3)bad - if someone blows a co2 canister at it
4)happy - when air quality returns to acceptable levels
5) (?) if it gets really cold?

Some randomization/variance in these sounds is encouraged to not be too repetitive.

skrubis, 2022-02-04:
here's a library for inspiration: https://www.arduino.cc/reference/en/libraries/cutebuzzersounds/

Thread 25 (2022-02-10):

Reduce OLED contrast on init

skrubis, 2022-02-10:
Due to incredible amounts of burn in caused by the somewhat static main screen of platformio fw running for maybe a day- please reduce the OLED contrast to a somewhat useable minimum on init

	i2c_command(0x81); // SSD1306_SETCONTRAST

festlv, 2022-02-14:
It seems to me that u8g2 library sets the contrast to maximum on startup.

badge.team's ssd1306 driver sets the contrast to 207 (range: 0-255). I would guess that this value is somewhat validated by badges, however, the real effect of this register's value also depends on bias resistor, which may differ (as the badges typically are using OLED directly, without the carrier board): https://forums.adafruit.com/viewtopic.php?t=38569#p573606

festlv, 2022-02-17:
After my screen was frozen for a day, it did experience burn-in with the previous contrast value (0xcf).
Reduced to 0x33 in https://github.com/open-lv/micropython/tree/0.0.8

Closed 2022-02-17.

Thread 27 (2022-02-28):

Append part of device MAC ID to the hotspot AP name to make them unique

kasparsd, 2022-02-28:
To avoid problems connecting to devices when multiple of them have hotspots enabled nearby we need to use unique AP names.

One solution is to append the last two bytes of the device MAC to the AP name such as `GaisaSargs03AB` or `GaisaSargs-03AB` here:

https://github.com/open-lv/air-guard/blob/bd06151d986bbe80923d18c140d2af601c506134/firmware/micropython/sargs.py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

kasparsd, 2022-02-28:
Can be done here https://github.com/open-lv/micropython/blob/39bf805c69e84e9c77e767989de3cdb7921e35e2/ports/esp32/boards/AIRGUARD/modules/network_manager.py or directly in `sargs.py`.

RonnyLV, 2022-02-28:
Fixed in https://github.com/open-lv/air-guard/commit/995cdb4d79f742ae6de5641e2b2abca483565a75

Closed 2022-02-28.

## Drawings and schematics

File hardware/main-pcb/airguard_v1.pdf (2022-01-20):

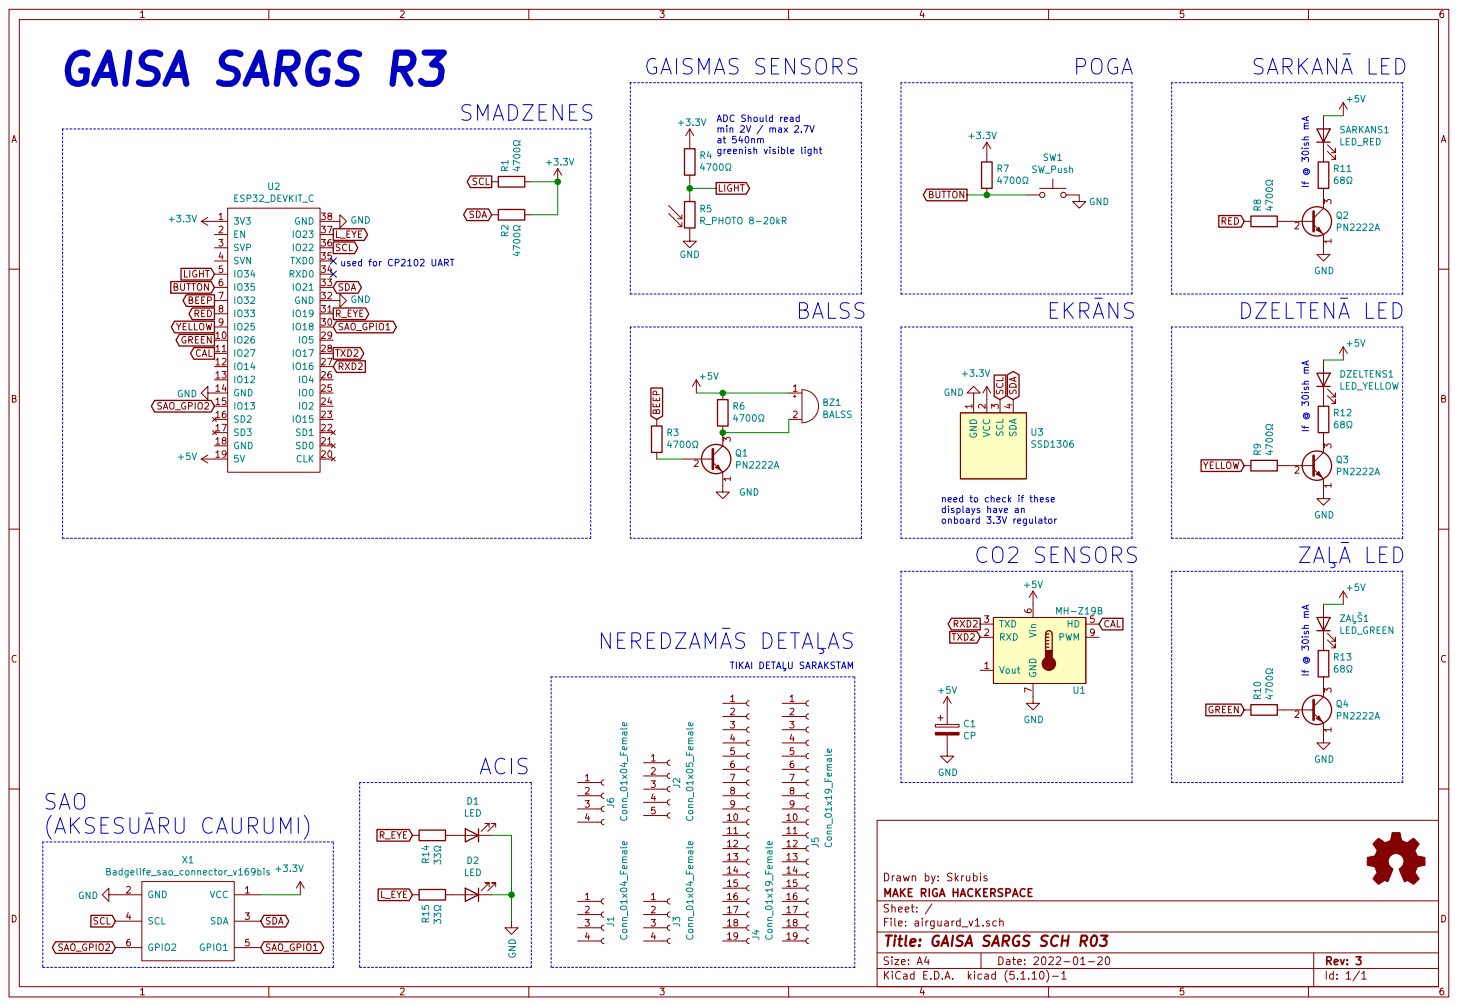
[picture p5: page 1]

ADC Should read min 2V / max 2.7V

at 540nm greenish visible light

need to check if these displays have an

3 Q4PN2222A R15 33 VCC 1 GND 2 SDA 3 SCL 4 GPIO1 5 GPIO2 6 X1 Badgelife_sao_connector_v169bis +3.3V GND GND

File: airguard_v1.sch Sheet: / MAKE RIGA HACKERSPACE Drawn by: Skrubis

Id: 1/1 Title: GAISA SARGS SCH R03

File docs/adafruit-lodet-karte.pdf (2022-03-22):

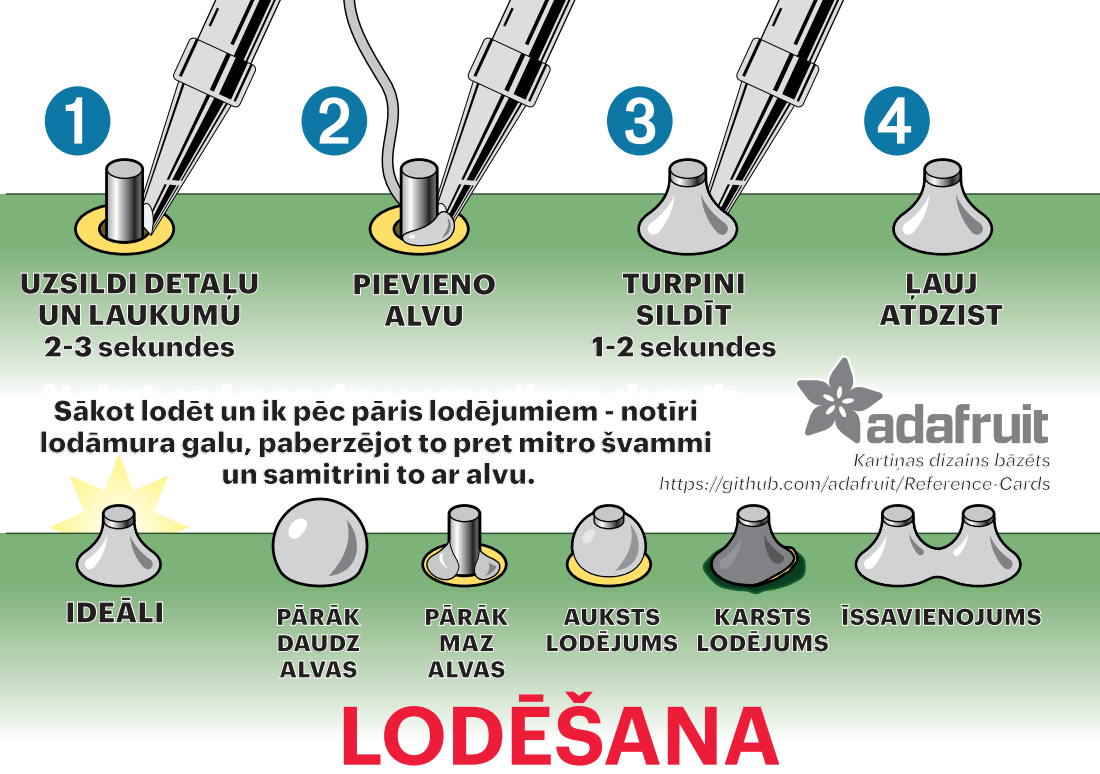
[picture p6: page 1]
un samitrini to ar alvu.; Kartiņas dizains bāzēts; TURPINI SILDĪT 1-2 sekundes; ĻAUJ ATDZIST; PIEVIENO ALVU; IDEĀLI; PĀRĀK; DAUDZ ALVAS; ĪSSAVIENOJUMS; MAZ ALVAS; AUKSTS LODĒJUMS; KARSTS LODĒJUMS

UZSILDI DETAĻU
UN LAUKUMU
2-3 sekundes
Sākot lodēt un ik pēc pāris lodējumiem - notīri
lodāmura galu, paberzējot to pret mitro švammi

https://github.com/adafruit/Reference-Cards
LODĒŠANA

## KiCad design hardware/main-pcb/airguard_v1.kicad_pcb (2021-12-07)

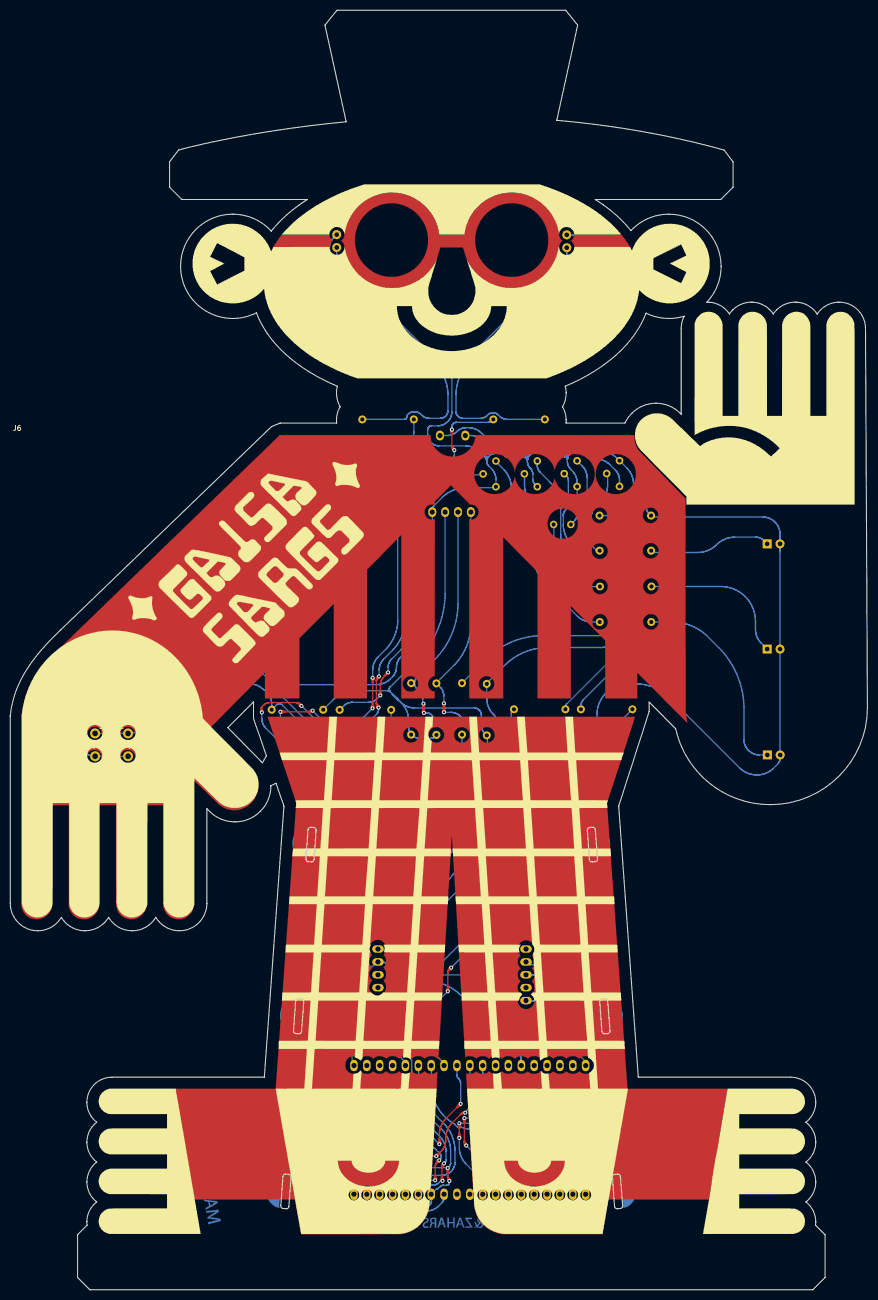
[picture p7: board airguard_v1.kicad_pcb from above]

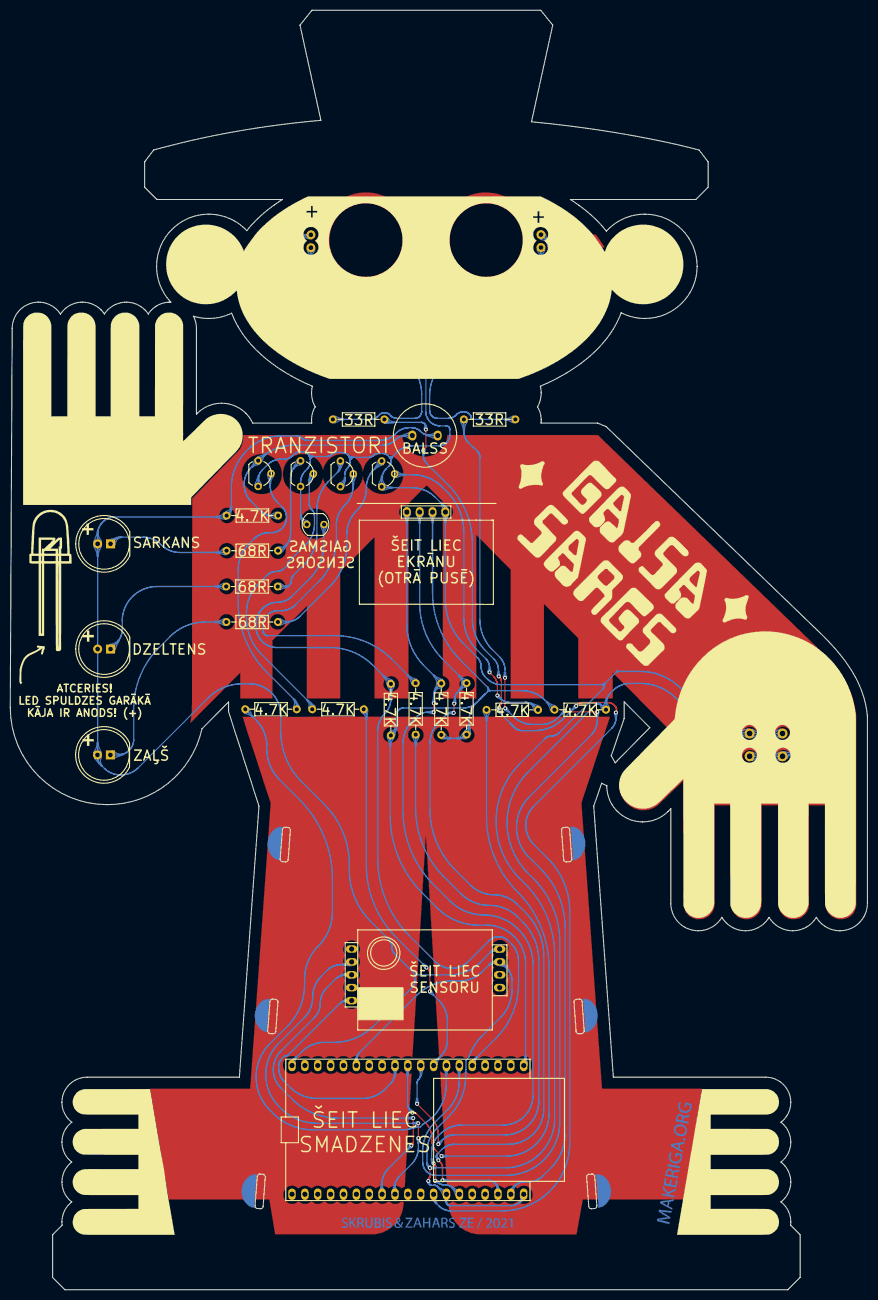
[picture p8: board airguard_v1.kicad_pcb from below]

Board: 2 copper layers, 169.1 x 252.5 mm, 35 parts (22 on the bottom side), 29 nets.

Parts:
BZ1: BALSS; buzzer-C360606
D1, D2: LED; LED_D3.0mm
DZELTENS: LED_YELLOW; LED_D10.0mm
J1, J3, J6: Conn_01x04_Female; Dummy_Empty
J4, J5: Conn_01x19_Female; Dummy_Empty
Q1, Q2, Q3, Q4: PN2222A; TO-92_Molded_Wide
R1, R2, R3, R4, R6, R7, R8, R9, R10: 4.7K; R_Axial_DIN0207_L6.3mm_D2.5mm_P10.16mm_Horizontal
R5: R_PHOTO 8-20kR; Resistor_LDR_5.1x4.3_RM3.4
R11, R12, R13: 68R; R_Axial_DIN0207_L6.3mm_D2.5mm_P10.16mm_Horizontal
R14, R15: 33R; R_Axial_DIN0207_L6.3mm_D2.5mm_P10.16mm_Horizontal
SARKANS: LED_RED; LED_D10.0mm
SW1: SW_Push; SW_PUSH_6mm_h5mm
U1: MH-Z19B; Winsen_MH-Z19B
U2: ESP32_DEVKIT_C
U3: EKRĀNS; SSD1306
ZAĻŠ: LED_GREEN; LED_D10.0mm
e: Val**; 02

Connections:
+3V3: R1.1, R2.1, R4.2, R7.2, U2.1, U3.2
+5V: BZ1.1, DZELTENS.2, R6.2, SARKANS.2, U1.6, U2.19, ZAĻŠ.2
BEEP: R3.2, U2.7
BUTTON: R7.1, SW1.1, U2.6
CAL: U1.5, U2.11
GND: D1.1, D2.1, Q1.1, Q2.1, Q3.1, Q4.1, R5.2, SW1.2, U1.7, U2.14, U2.32, U2.38, U3.1
GREEN: R10.2, U2.10
LIGHT: R4.1, R5.1, U2.5
L_EYE: R15.2, U2.37
unnamed: BZ1.2, Q1.3, R6.1
unnamed: D1.2, R14.1
unnamed: D2.2, R15.1
unnamed: DZELTENS.1, R12.2
unnamed: Q1.2, R3.1
unnamed: Q2.2, R8.1
unnamed: Q2.3, R11.1
unnamed: Q3.2, R9.1
unnamed: Q3.3, R12.1
unnamed: Q4.2, R10.1
unnamed: Q4.3, R13.1
unnamed: R11.2, SARKANS.1
unnamed: R13.2, ZAĻŠ.1
RED: R8.2, U2.8
RXD2: U1.3, U2.27
R_EYE: R14.2, U2.31
SCL: R1.2, U2.36, U3.3
SDA: R2.2, U2.33, U3.4
TXD2: U1.2, U2.28
YELLOW: R9.2, U2.9

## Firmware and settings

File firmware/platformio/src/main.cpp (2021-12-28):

#include <Arduino.h>
#include <AsyncDelay.h>
#include <MHZ19.h>  // https://github.com/WifWaf/MH-Z19
#include <Wire.h>
#include <U8g2lib.h>
#include <analogWrite.h> // https://github.com/ERROPiX/ESP32_AnalogWrite
//#define analogWrite ledcWrite // ja lieto platform.io - TIL tam nepatīk analogWrite

U8G2_SSD1306_128X64_NONAME_1_HW_I2C u8g2(U8G2_R0, /* reset=*/ U8X8_PIN_NONE);
MHZ19 sensors;

//#include "grafikas.h"

//Lai GAISA SARGA smadzenes zinātu, kur atrodas tā ķermeņa daļas- tās ir jādefinē
const int SARKANS = 33; //LED sarkanais
const int DZELTENS = 25; //LED dzeltenais
const int ZALS = 26; //LED zaljais
const int BALSS = 32; //piikstulis
const int GAISMA = 34; //fotorezistors
const int ROKA = 35; //poga uz rokas
const int EKRANS_DATI = 21; //OLED SDA
const int EKRANS_PULKSTENS = 22; //OLED SCL
const int KREISAA_ACS = 23; //LED kreisaa acs
const int LABAA_ACS = 19; //LED labaa acs

void personiba(int ppm, int gaisma){
  u8g2.setFont(u8g2_font_open_iconic_human_6x_t);
  u8g2.drawGlyph(1, 48, 66);	
  u8g2.setFont(u8g2_font_logisoso32_tf);
  if(ppm <= 1000){
    u8g2.setCursor(48+9, 42);
    u8g2.print(ppm);
  } else {
    u8g2.setCursor(49, 42);
    u8g2.print(ppm);
  }

  u8g2.setCursor(14,35);
  u8g2.setColorIndex(0);
  u8g2.setFont(u8g2_font_logisoso16_tf);
  u8g2.print("CO");
  u8g2.setCursor(33,22);
  u8g2.setColorIndex(0);
  u8g2.setFont(u8g2_font_8x13_tf);
  u8g2.print("2");

  u8g2.setFont(u8g2_font_logisoso16_tf);
  u8g2.setColorIndex(1);

  if(ppm == 0){
      analogWrite(BALSS, 0);
      digitalWrite(SARKANS, LOW);
      digitalWrite(DZELTENS, LOW);
      digitalWrite(ZALS , LOW);
      u8g2.setCursor(15,62);
      u8g2.print("Sensors iesilst");
      digitalWrite(ZALS, HIGH);
  }
  if(ppm > 0 && ppm <= 400){
      analogWrite(BALSS, 0);
      digitalWrite(SARKANS, LOW);
      digitalWrite(DZELTENS, LOW);
      digitalWrite(ZALS , LOW);
      u8g2.setCursor(15,62);
      u8g2.print("LABS GAISS!");
      digitalWrite(ZALS, HIGH);
  }
  if(ppm <= 999 && ppm >= 401){
      analogWrite(BALSS, 0);
      digitalWrite(SARKANS, LOW);
      digitalWrite(DZELTENS, LOW);
      digitalWrite(ZALS , LOW);
      u8g2.setCursor(15,62);
      u8g2.print("ATVER LOGU!");
      digitalWrite(DZELTENS, HIGH);
  }
  if(ppm <= 9999 && ppm >= 1000){
      digitalWrite(SARKANS, LOW);
      digitalWrite(DZELTENS, LOW);
      digitalWrite(ZALS , LOW);
      u8g2.setCursor(48,62);
      u8g2.print("AARRGH!");
      digitalWrite(SARKANS, HIGH);
      analogWrite(BALSS, 200);
  }
  

  //delay(3000);
  
  	
  //u8g2.print("ppm");	
}

void rita_rosme(){

  digitalWrite(SARKANS, HIGH);
  digitalWrite(DZELTENS, HIGH);
  digitalWrite(ZALS, HIGH);
  delay(1000);
  digitalWrite(SARKANS, LOW);
  digitalWrite(DZELTENS, LOW);
  digitalWrite(ZALS , LOW);
  delay(500);
  analogWrite(BALSS, 127);
  delay(200);
  analogWrite(BALSS, 200);
  delay(800);
  analogWrite(BALSS, 0);
  analogWrite(KREISAA_ACS, 200);
  analogWrite(LABAA_ACS, 200);
}

void setup() {
 pinMode(KREISAA_ACS, OUTPUT);
 pinMode(LABAA_ACS, OUTPUT);
 pinMode(SARKANS, OUTPUT);
 pinMode(DZELTENS, OUTPUT);
 pinMode(ZALS, OUTPUT);
 pinMode(BALSS, OUTPUT);
 pinMode(GAISMA, INPUT);
 pinMode(ROKA, INPUT);
 Serial.begin(115200);
 Serial2.begin(9600);
 sensors.begin(Serial2);
 sensors.autoCalibration(); //ieslēdzu auto kalibrāciju, izpētīt vai nevajag uztaisīt manuālas 400ppm kalibrācijas rutīnu. info libas git calibration example
 u8g2.begin();  
 u8g2.enableUTF8Print();

 rita_rosme();
}

void loop() {
 int co2_limenis = sensors.getCO2();
 int telpas_gaisums = analogRead(GAISMA);
 //char ppm_teksts[9];
 //sprintf(ppm_teksts, "%d", sensora_vertiba);
 Serial.println(co2_limenis);
  
  u8g2.firstPage();
  do {
    personiba(co2_limenis, telpas_gaisums);
  } while ( u8g2.nextPage() );

}

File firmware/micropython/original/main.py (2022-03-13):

import gc

import uasyncio

import logging
from . import sargsui
from . import sargs
from . import plot
from . import utils
from . import portal
import time

log = logging.getLogger("main")

sargs = sargs.setup()


async def measurements():
    while True:
        measurement = await sargs.perform_co2_measurement()
        sargs.handle_co2_measurement(measurement)

        if measurement <= 1000:
            sargs.led_yellow.off()
            sargs.led_red.off()

            sargs.led_green.on()
        elif measurement <= 1400:
            sargs.led_green.off()
            sargs.led_red.off()

            sargs.led_yellow.on()
        elif measurement > 1400:
            sargs.led_green.off()
            sargs.led_yellow.off()

            sargs.led_red.on()

        await uasyncio.sleep(5)


def set_global_exception():
    def handle_exception(loop, context):
        import sys
        print(context)
        sys.print_exception("Unhandled exception in async function: %s" % context["exception"])
        sys.exit()

    loop = uasyncio.get_event_loop()
    loop.set_exception_handler(handle_exception)


async def setup():
    import gc
    log.info("mem_free=%d" % gc.mem_free())
    log.info("Setting up Sargs")

    set_global_exception()  # Debug aid

    await sargs.setup()

    log.info("mem_free=%d" % gc.mem_free())
    log.info("Animating Screen and LEDs")
    # Ekrāna pārbaude
    await sargs.draw_centered_text(21, 'GAISA SARGS')
    await sargs.draw_centered_text(32, 'VERSIJA ' + sargs.version[:8])
    sargs.screen.flush()

    log.info("mem_free=%d" % gc.mem_free())
    # Pārbaude pēc ieslēgšanās: ieslēdzam visas gaismas diodes pēc kārtas un pēc tam izslēdzam tās
    pins = [sargs.led_green, sargs.led_yellow, sargs.led_red, sargs.led_right_eye, sargs.led_left_eye]
    for p in pins:
        p.on()
        await uasyncio.sleep(0.25)
    await uasyncio.sleep(1)
    for p in reversed(pins):
        p.off()
        await uasyncio.sleep(0.25)

    log.info("mem_free=%d" % gc.mem_free())
    log.info("Setting up tasks")
    uasyncio.create_task(sargs.run())
    uasyncio.create_task(metrics()())

    log.info("mem_free=%d" % gc.mem_free())
    await measurements()


def metrics():
    ncalls = 0
    max_d = 0
    min_d = 100_000_000
    tot_d = 0
    st = 'Max {}us Min {}us Avg {}us No. of calls {} Freq {}'

    async def func():
        nonlocal ncalls, max_d, min_d, tot_d
        while True:
            tstart = time.ticks_us()
            t_last = None
            while time.ticks_diff(t := time.ticks_us(), tstart) < 10_000_000:
                await uasyncio.sleep(0)
                if ncalls:
                    dt = time.ticks_diff(t, t_last)
                    max_d = max(max_d, dt)
                    min_d = min(min_d, dt)
                    tot_d += dt
                ncalls += 1
                t_last = t
            log.info(st.format(max_d, min_d, tot_d // ncalls, ncalls, ncalls // 10))
            gc.collect()
            log.info('mem_free = {}'.format(gc.mem_free()))
            ncalls = 0
            max_d = 0
            min_d = 100_000_000
            tot_d = 0

    return func


def run():
    gc.collect()
    try:
        uasyncio.run(setup())
    except KeyboardInterrupt:
        event_loop = uasyncio.get_event_loop()
        event_loop.close()

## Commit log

2021-09-23 Add chat button
2021-09-27 Adding skeleton for project hardware v1
    [airguard_v1.kicad_pcb, airguard_v1.sch]
2021-09-27 Adding KiCad .gitignore to the hardware folder
2021-09-27 Adding ESP32 DEVKIT C library and footprint files - just designed from scratch according to datasheets, feel free to reverify
2021-09-27 Foolproofing the MH-Z19B footprint - enlarging pads and adding soldermask to top so that they can't be soldered incorrectly
2021-09-27 Adding new symbols to the schematic and PCB - no other work done
    [airguard_v1.kicad_pcb, airguard_v1.sch]
2021-09-27 Adding SSD1306 display symbols and footprints from https://github.com/pforrmi/KiCad-SSD1306-128x64
2021-09-27 Adding 3D models for the OLED, CO2 sensor and ESP32 board
    [MH-Z19C.STEP, OLED TFT 0.96 inch 64x128 monochrome.STEP]
2021-09-27 Adding the OLED and all 3d models; connecting some of the signals to the corresponding ESP32 pins
    [airguard_v1.kicad_pcb, airguard_v1.sch]
2021-09-28 Sanity check - 0.8mm drills weren't enough for the footprints I used, switched them to 1mm drills instead
    [airguard_v1.kicad_pcb]
2021-12-07 added HW 0.2
    [LCSC_Bom_0.csv, MH-Z19C.STEP, OLED TFT 0.96 inch 64x128 monochrome.STEP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]
2021-12-18 added very drafty Bill Of Materials
    [BOM-18-12-21.xlsx]
2021-12-22 updated readme.md, added schematic pdf
    [airguard_v1.csv]
2021-12-25 removed drug baggies for PC ppl
    [BOM-18-12-21.xlsx, PRELIMINARY-PROJECT-BOM-251221.xlsx]
2022-01-08 Refs #10: Fix incorrect checksum calculation for packets with checksums of 0x00
    [mhz19.py]
2022-01-10 uPy: Refactor main thread into separate functions, fix unhandled WiFi exceptions (e.g. network not found)
    [sargs.py]
2022-01-10 uPy: fix trivial but important issues caught by pycharm (inconsistent indentation, missing attributes)
    [mhz19.py, sargs.py, utils.py]
2022-01-10 Introduce the device ID helper
2022-01-10 Ignore flashed device list
2022-01-11 uPy: implement manual calibration request via button press/confirmation on screen
2022-01-11 uPy: document the manual calibration process
2022-01-12 Fixed bug in device auto-detection
2022-01-14 uPy: disable ABC calibration by default
2022-01-14 uPy: fix blinking of R/G/B status LEDs due to context switching
    Previously the code in main.py turned off all LEDs and then turned on
    the needed one based on sensor readings. However, if execution context
    is switched to background thread after LEDs have been turned off, but
    before the new one was turned on, and the operation in background
    thread was time-consuming (WiFi re-association, publishing to mqtt)
    visible blinking of the LED could be observed.
    [main.py]
2022-01-14 uPy: optional temp. reporting via mqtt, improved sensor status report
    During warmup, LCD does not congratulate you on having fresh air
2022-01-20 updated main board to R3
    [airguard_v1-B_Cu.gbr, airguard_v1-B_Mask.gbr, airguard_v1-B_SilkS.gbr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]
2022-01-20 plot sch
    [airguard_v1.sch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]
2022-01-20 cleanup rear gerber folder
    [gaisa-sargs-rear-2-B_Cu.gbr, gaisa-sargs-rear-2-B_Mask.gbr, gaisa-sargs-rear-2-B_Paste.gbr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]
2022-01-20 added draugs pcb
2022-01-20 draugs pcb img
2022-01-20 updated side pcb to have cutout for weird devkitc interpretations
    [gaisa-sargs-side-pcb-2-B_Cu.gbr, gaisa-sargs-side-pcb-2-B_Mask.gbr, gaisa-sargs-side-pcb-2-B_Paste.gbr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]
2022-01-24 uPy: add eye animations on button press and light sensor
2022-01-25 tools/flasher: migrate to micropython v1.18, fix flashing process
    flash.sh:
    * ignore empty build dir (failed with non-existant filename)
    * add build dir to .gitignore
    * mpremote created a build folder on device and copied files there
2022-01-29 Define the calibration service
2022-01-29 Add an ID for the whole sensor item
2022-02-03 added sponsor logos -mask only-
    [airguard_v1-aranet-logo.kicad_pcb, airguard_v1-erica-logo.kicad_pcb, airguard_v1-nsa-logo.kicad_pcb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]
2022-02-05 fixed dash in rear pcb, fixed nsa logo gerber archive
    [gaisa-sargs-rear-2.kicad_pcb]
2022-02-06 uPy Portal: Added Vue.js sample app
2022-02-09 uPy Sargs: Returning buzzer functionality
    [sargs.py]
2022-02-11 uPy Portal: Default `/` page fix
    [portal.py]
2022-02-11 mPy: migrate from pythonic ssd1306 driver to display module from badge.team
2022-02-15 moved BOM to HW, removed non relevant spreadsheets
    [PRELIMINARY-PROJECT-BOM-251221.xlsx]
2022-02-15 mPy: remove files that are frozen, copy assets in flash.sh
    See open-lv/micropython/ports/esp32/boards/AIRGUARD/modules for the
    source code of removed python files.
2022-02-15 uPy: Fix async buzzer calls
    [sargsui.py]
2022-02-17 mPy: draw degree symbol in the correct place, based on width of displayed value
    [sargsui.py]
2022-02-17 flash.sh: reboot device after flashing
2022-02-17 mPy: remove uart selection as I now have the same hw as kit
2022-02-17 flash.sh: don't overwrite the file containing flashed devices, register firmware versions as well
2022-02-17 mPy: change main screen to large beating heart, add screen switching
2022-02-18 created folder for current gerbers
2022-02-18 added gerber folder readme
2022-02-18 added gerber folder readme vendors
2022-02-18 add rear pcb readme
2022-02-18 added known bugs for rear pcb
2022-02-18 add side pcb readme
2022-02-18 mPy: speed up everything, invert eye functionality, fix heartbeat arrhythmia
    [sargs.py, sargsui.py, utils.py]
2022-02-21 uPy Stubs: network_manager: Reset service only if once connected
    [network_manager.py]
2022-02-28 mPy: center CO2 sensor failed message
    [sargs.py]
2022-02-28 mPy: fix LCD, CO2 sensor error handling
    [sargs.py]
2022-03-06 uPy: Fix missing measurement state update
    [sargs.py]
2022-03-07 uPy: add async possibility to mhz19 driver
2022-03-13 uPy OTA: Fix incorrect function reference
    [main.py, ota_utils.py]
2022-03-13 uPy OTA: Fix installer issues
    [ota.py]
2022-03-13 uPy: Fix versioning display
    [main.py, sargs.py]
2022-03-13 uPy OTA: Fix other version removal function
    [ota_utils.py]
2022-03-15 uPy OTA: Remove threading in favour of thread safety
2022-03-15 uPy OTA: Fix reset stage `remove other versions`
    [boot.py]
2022-03-15 uPy: fix ota prompt timeout in sargsui
    [sargsui.py]
2022-03-16 Add release list to protal
    Add update to lates button to release list
    Show new version badge in navigation
2022-03-20 uPy Flasher: Added label printing capabilities
2022-03-21 added printed manual
2022-03-22 soldering card
